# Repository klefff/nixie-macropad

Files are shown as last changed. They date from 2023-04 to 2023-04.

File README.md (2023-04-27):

# nixie-macropad

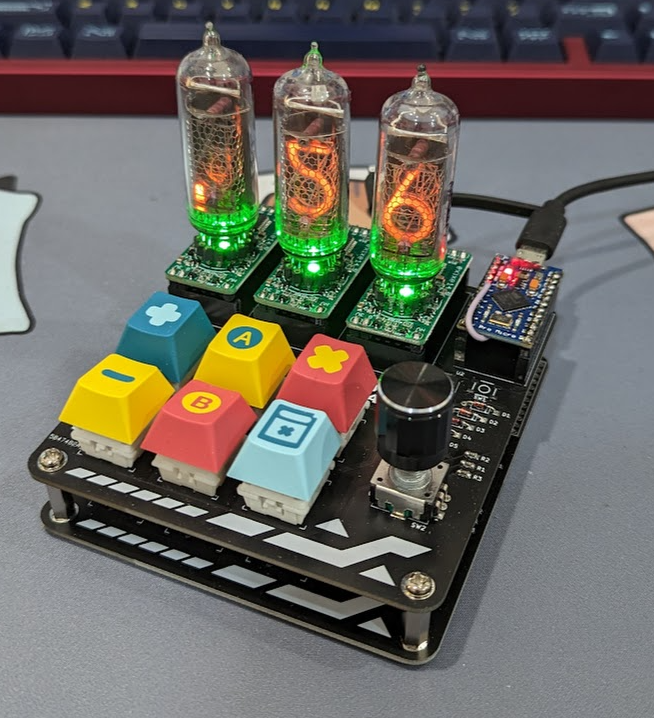
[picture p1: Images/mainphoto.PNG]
</p>

Simple 2x3 macropad with encoder that has a 3 digit nixie tube display that can be programmed for various functions over QMK.

## Usage:
Feel free to try replicate with care, as this is an unpolished proof of concept that I will probably build on later. Enjoy!

### Hardware Notes:
- Not sure but it seems the boards that I am using to drive the Nixie tubes [might be discontinued](https://www.tindie.com/products/dekuNukem/exixe-miniture-nixie-tube-driver-modules/). However the developer open-sourced them, so you might be able to make them yourself. (Planning to make my own for future builds)

## Main Features:
- 3x IN-14 Nixie Tubes with numbers 0-9 plus left comma
- Uses [QMK](https://qmk.fm/)
- Display current volume of connected Windows device [via RAWHID](https://github.com/BlankSourceCode/qmk-hid-display)
- EC11 Encoder + button
- 2x3 Macropad with Kailh Hotswap
- Only USB connected to PC needed

## Software Installation:
### Windows Node Script:
1. Download the 'Node Script' folder
1. Follow the steps in 'Development Setup' and/or 'Using the Script' from [BlankSourceCode's repo](https://au.element14.com/harwin/m20-7821246/connector-rcpt-12pos-2-54mm-1row/dp/3225929) 

### QMK:
1. You need to flash the Pro Micro with custom QMK firmware
    - Fork: [Use my fork](https://github.com/klefff/qmk_firmware/)
    - How to flash: [QMK Docs](https://docs.qmk.fm/#/newbs_flashing)
1. Build for [Phi (Default)](https://github.com/klefff/qmk_firmware/tree/master/keyboards/phi)

## Hardware:
### Before Assembling:
1. For the Exixes, you need to attach the Nixie tubes to the boards. 
    - I just soldered machine sockets to the boards and shoved the Nixie tube pins into the sockets (gingerly)
    - Or follow their [recommended method](https://github.com/dekuNukem/exixe/blob/master/getting_started.md)
### Assembly
1. Make the custom PCBs (needs 2, or make a case)
1. Solder on the required components below (see pictures)
1. Assemble such that two of the custom PCBs make a basic case thing
1. Choose some cool keycaps and knob

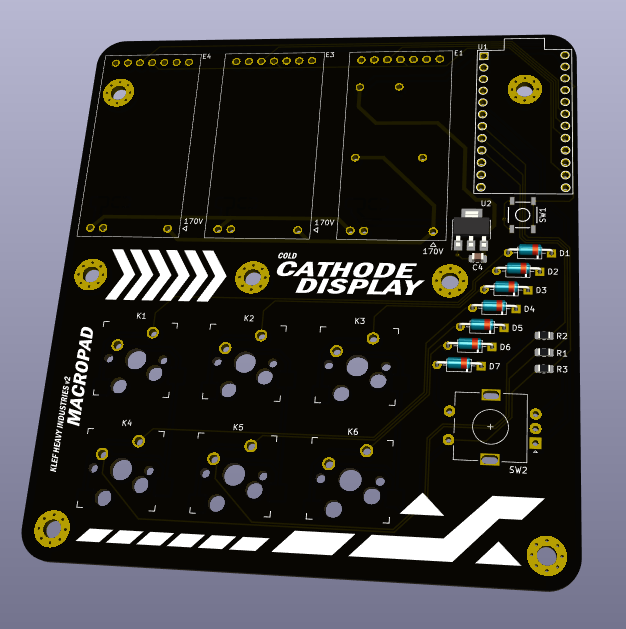
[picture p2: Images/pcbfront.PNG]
</p>
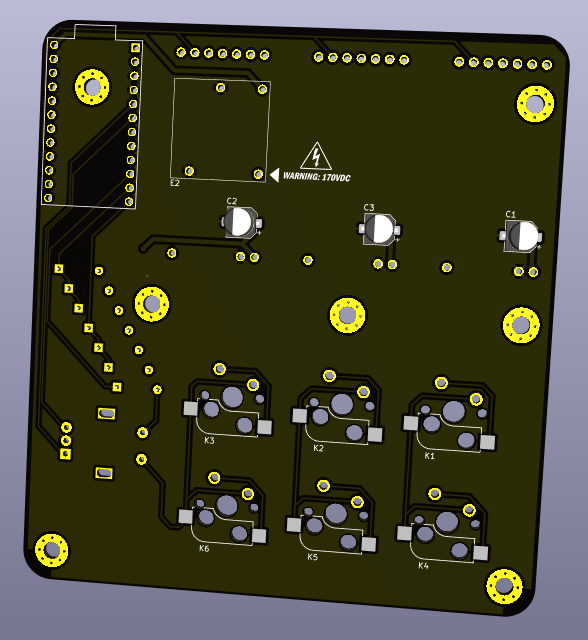
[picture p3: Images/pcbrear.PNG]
</p>
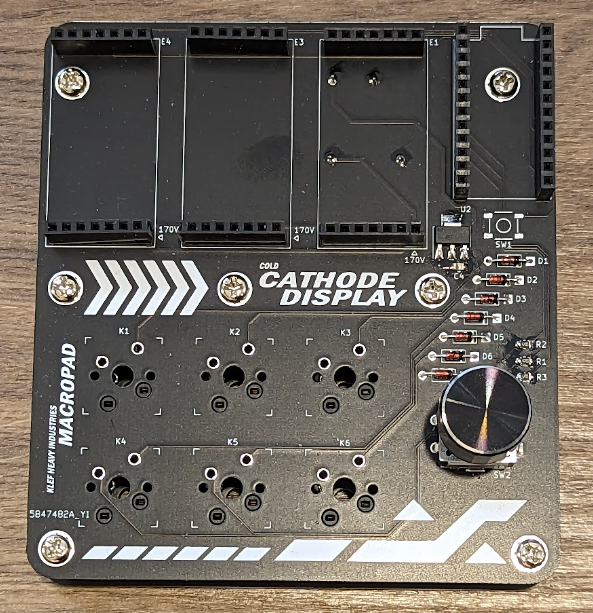
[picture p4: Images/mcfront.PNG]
</p>
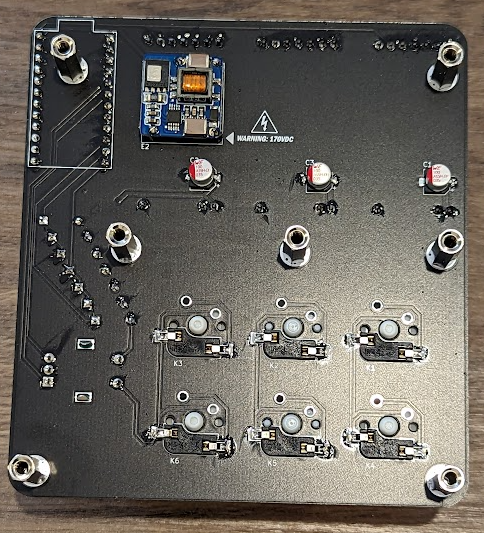
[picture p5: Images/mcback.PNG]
</p>

## Bill of Materials:
- 2x Custom PCBS
    - Sandwich with 7x 15mm standoffs (M3 Size)
- 3x [Exixe](https://github.com/dekuNukem/exixe)
    - Nixie tube driver modules with SPI communication
- 3x IN-14 Nixie Tubes with 0-9 digit and left comma (at least)
- 1x Pro Micro or similar pinout with QMK support
- 2x Custom base PCB that doubles as stand
    - See PCB build files
- 6x Kailh Hotswap switch sockets
- 1x [2.5-15VDC to 170VDC DC-DC convertor](https://omnixie.com/products/nch8200hv-nixie-hv-power-module) or similar
- 1x Any type of EC11 rotary encoder
    - [I used this one](https://www.digikey.com.au/en/products/detail/bourns-inc/PEC11R-4020K-S0024/4499637)
- 1x [SMD 3.3V Voltage Regulator](https://au.element14.com/stmicroelectronics/ld1117s33ctr/ic-v-reg-ldo-3-3v-smd/dp/146777902)
    - Needed to power the Exixes
- 3x 10uF [Electrolytic Capacitors](https://au.element14.com/wurth-elektronik/865230542002/cap-10-f-35v-smd/dp/2466435)
    - Required for the Voltage Reg
- 1x 0.1uF [Ceramic Capacitor](https://au.element14.com/yageo/cc0805krx7r8bb104/cap-0-1-f-25v-10-x7r-0805/dp/644249)
- 7x [Diodes](https://www.digikey.com.au/en/products/detail/onsemi/1N4148/458603)
- 3x [470 Ohm SMD Resistors](https://au.element14.com/multicomp-pro/mc0805s8f4700t5e/res-thick-film-470r-1-0-125w-0805/dp/1632491)
- Some 2.54mm pitch connectors (if you don't want to direct solder)
    - I like [machine sockets](https://www.digikey.com.au/en/products/detail/adam-tech/SMC-1-40-1-GT/9831942) but normal ['Arduino'-esque ones are good too](https://au.element14.com/harwin/m20-7821246/connector-rcpt-12pos-2-54mm-1row/dp/3225929)
    - 3x 7 pin for Exixe comms
    - 2x 12 pin for Pro Micro
    - 7x 1 pin (if you can find them or just cut bigger ones)
        - For 170V DC-DC convertor and Exixe 170V
    - 2x 2 pin for Exixe 3V
    - For the above 2, you can also just get 7 pin ones and take out the middle 4 pins
- Some keycaps
- An encoder knob

## Additional:
### Housekeeping:
- Every ~15 mins the tubes will cycle all digits to reduce change of cathode poisoning

### Future Work:
- Possible adding VIA capabilities for flashing
- Adding more uses for the 3 tube digits; current weather, CPU usage etc
- Adding another digit for RTC time
- Bluetooth/Wireless with battery

## References:
- [Exixe](https://github.com/dekuNukem/exixe)
- [RAW HID communication via node script](https://github.com/BlankSourceCode/qmk-hid-display)

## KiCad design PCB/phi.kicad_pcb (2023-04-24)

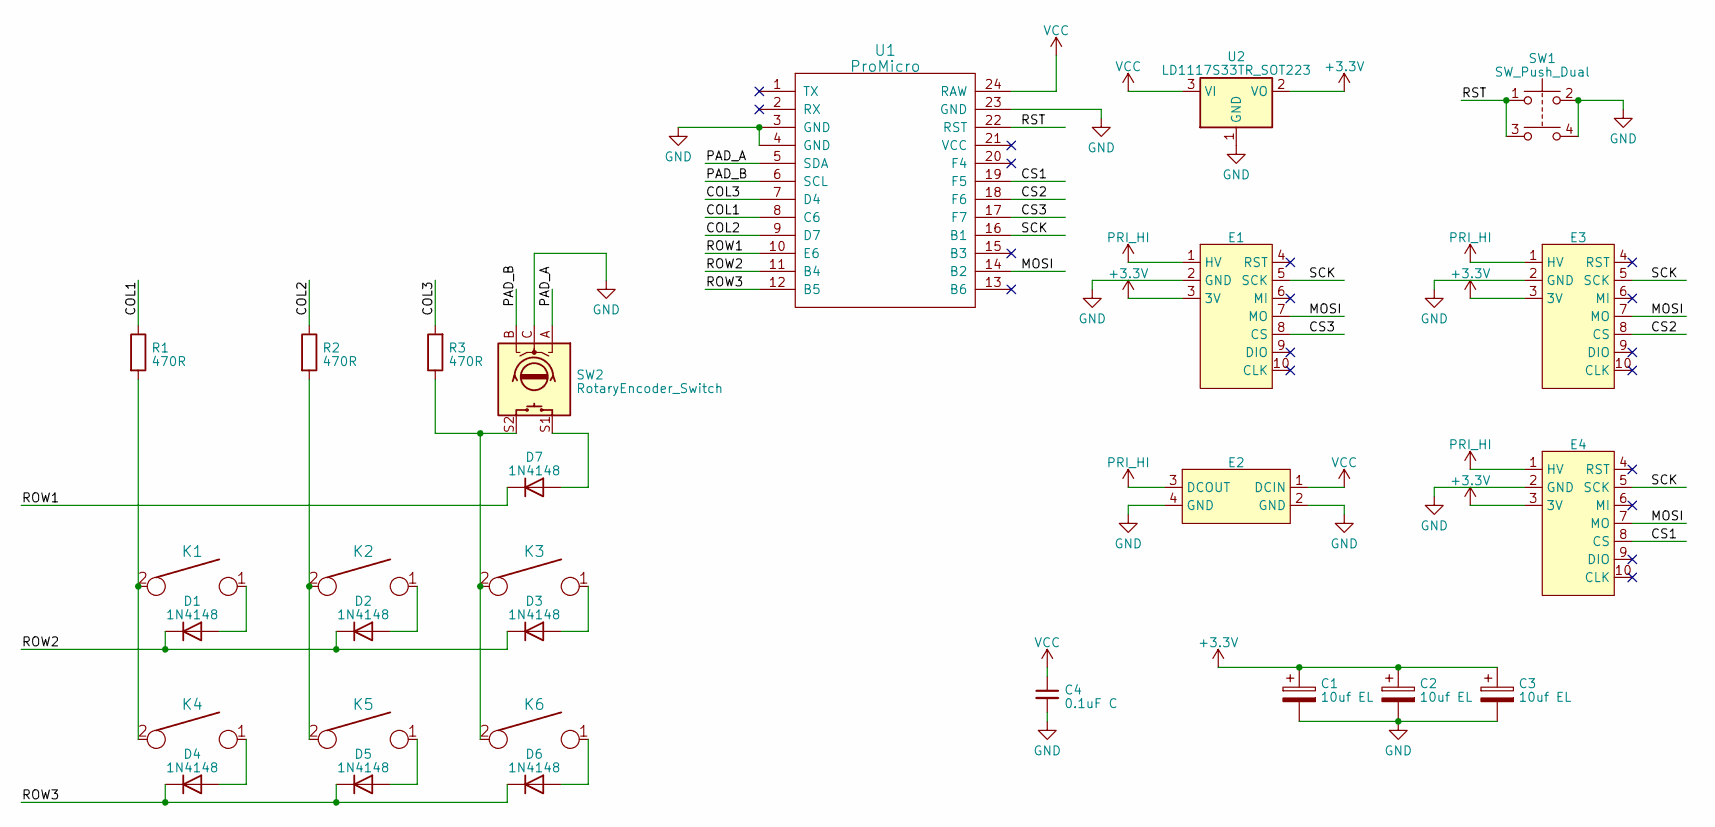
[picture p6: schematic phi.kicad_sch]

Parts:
C1, C2, C3: 10uf EL; CP_Elec_5x5.8
C4: 0.1uF C; C_0201_0603Metric_Pad0.64x0.40mm_HandSolder
D1, D2, D3, D4, D5, D6, D7: 1N4148; D_DO-35_SOD27_P7.62mm_Horizontal
E1, E3, E4: exixe14
E2: NCH8200HV
K1, K2, K3, K4, K5, K6: KEYSW; SW_Cherry_MX_1.00u_PCB
R1, R2, R3: 470R; R_0805_2012Metric_Pad1.20x1.40mm_HandSolder
SW1: SW_Push_Dual; TACTILE_SWITCH_SMD_5.2MM
SW2: RotaryEncoder_Switch; RotaryEncoder_Alps_EC11E-Switch_Vertical_H20mm
U1: ProMicro
U2: LD1117S33TR_SOT223; SOT-223-3_TabPin2

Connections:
+3.3V: C1.1, C2.1, C3.1, E1.3 (3V), E3.3 (3V), E4.3 (3V), U2.2 (VO)
/COL1: R1.1, U1.8 (C6)
/COL2: R2.1, U1.9 (D7)
/COL3: R3.2, U1.7 (D4)
/CS1: E4.8 (CS), U1.19 (F5)
/CS2: E3.8 (CS), U1.18 (F6)
/CS3: E1.8 (CS), U1.17 (F7)
/MOSI: E1.7 (MO), E3.7 (MO), E4.7 (MO), U1.14 (B2)
/PAD_A: SW2.A, U1.5 (SDA)
/PAD_B: SW2.B, U1.6 (SCL)
/ROW1: D7.1 (K), U1.10 (E6)
/ROW2: D1.1 (K), D2.1 (K), D3.1 (K), U1.11 (B4)
/ROW3: D4.1 (K), D5.1 (K), D6.1 (K), U1.12 (B5)
/RST: SW1.1, SW1.3, U1.22 (RST)
/SCK: E1.5 (SCK), E3.5 (SCK), E4.5 (SCK), U1.16 (B1)
GND: C1.2, C2.2, C3.2, C4.2, E1.2 (GND), E2.2 (GND), E2.4 (GND), E3.2 (GND), E4.2 (GND), SW1.2, SW1.4, SW2.C, U1.3 (GND), U1.4 (GND), U1.23 (GND), U2.1 (GND)
unnamed: D1.2 (A), K1.1
unnamed: D2.2 (A), K2.1
unnamed: D3.2 (A), K3.1
unnamed: D4.2 (A), K4.1
unnamed: D5.2 (A), K5.1
unnamed: D6.2 (A), K6.1
unnamed: D7.2 (A), SW2.S1
unnamed: K1.2, K4.2, R1.2
unnamed: K2.2, K5.2, R2.2
unnamed: K3.2, K6.2, R3.1, SW2.S2
PRI_HI: E1.1 (HV), E2.3 (DCOUT), E3.1 (HV), E4.1 (HV)
VCC: C4.1, E2.1 (DCIN), U1.24 (RAW), U2.3 (VI)

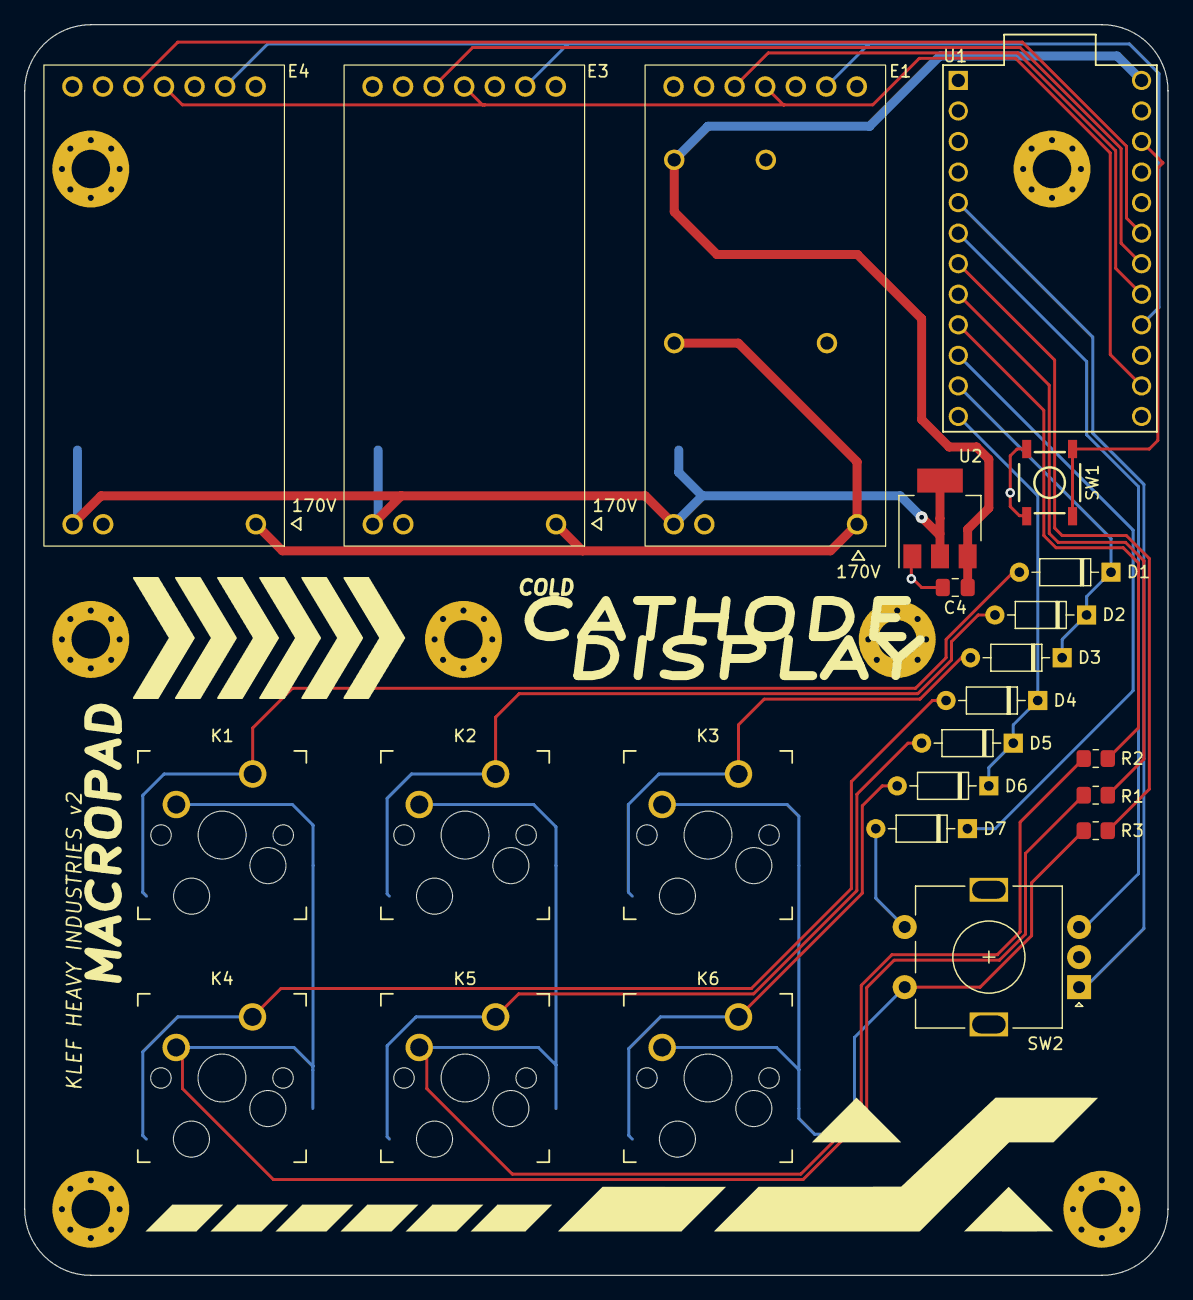
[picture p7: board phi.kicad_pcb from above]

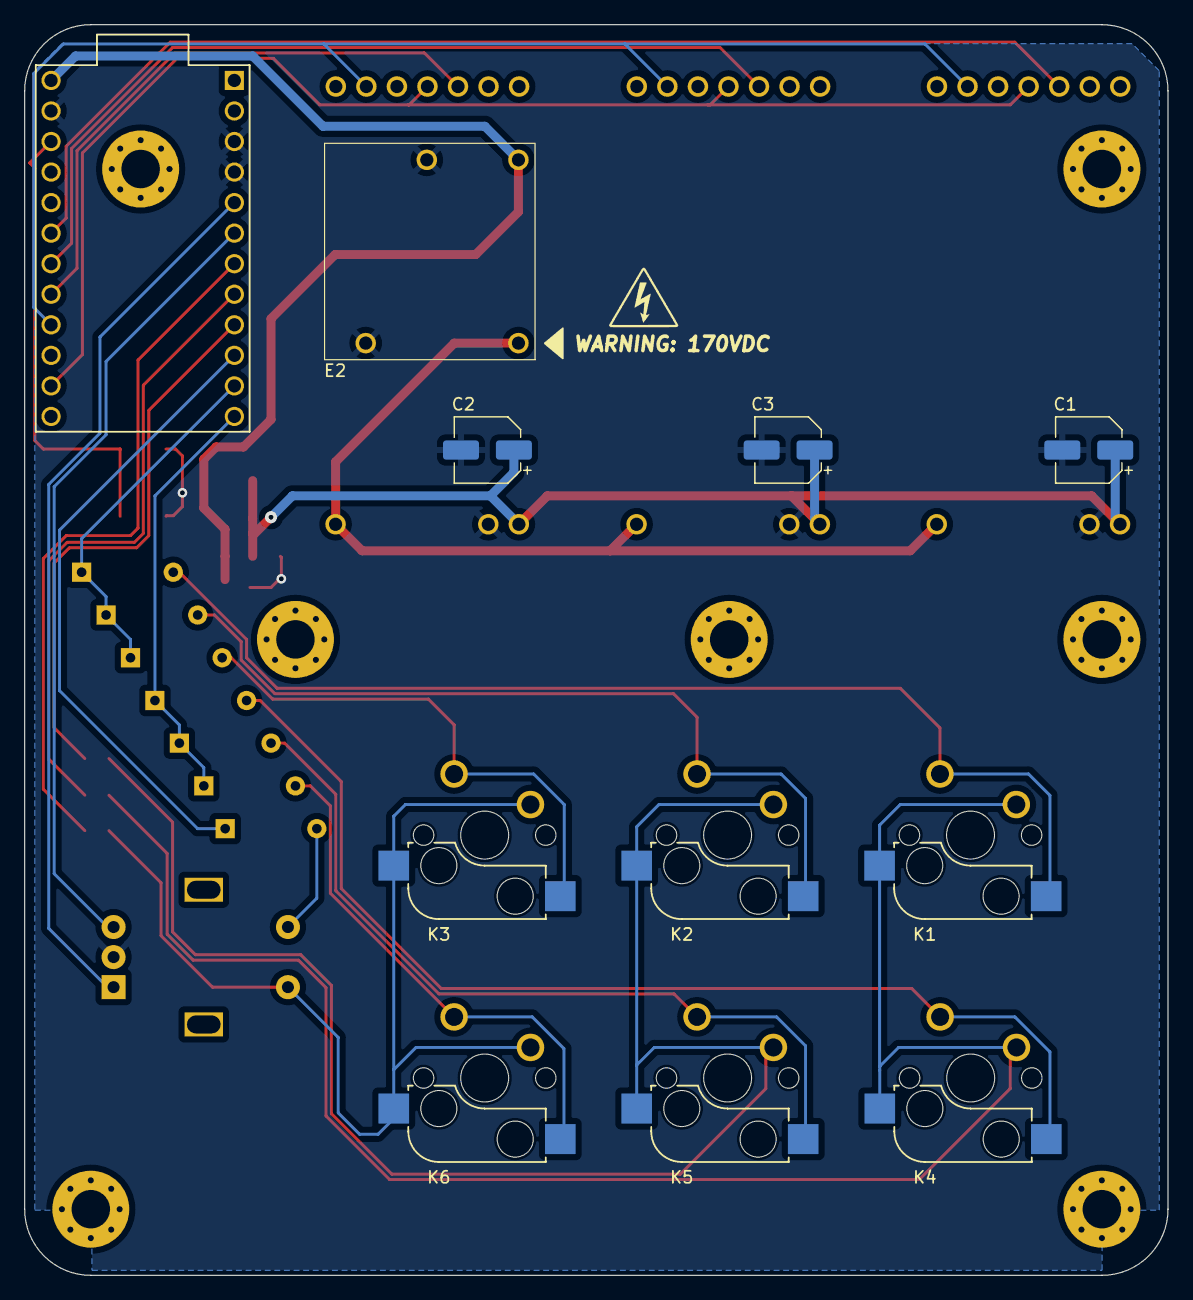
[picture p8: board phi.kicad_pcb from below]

Board: 2 copper layers, 95.1 x 104.0 mm, 28 parts (4 on the bottom side), 28 nets.

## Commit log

2023-04-24 added pcb files
    [phi-B_Cu.gbl, phi-B_Mask.gbs, phi-B_Paste.gbp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]
2023-04-25 added tube protection
2023-04-26 moved tube protection to qmk
2023-04-27 completely moved tube refresh to qmk
